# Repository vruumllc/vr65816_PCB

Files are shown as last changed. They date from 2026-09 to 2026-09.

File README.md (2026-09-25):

# vr65816

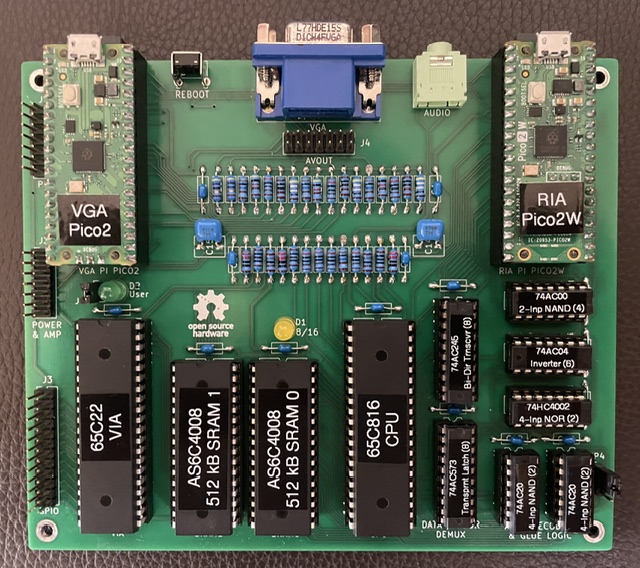
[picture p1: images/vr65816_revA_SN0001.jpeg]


WDC 65C816 Single Board Retro-Computer compatible with [Rumbledethump's Picocomputer Architecture](https://picocomputer.github.io/)

This project is based on [Rumbledethump's Picocomputer 6502 design](https://github.com/picocomputer/schematic), so he gets top billing. 

That said, any flaws are my fault, 'cause his board works GREAT! 

Report any problems to me using the ['Issues'](https://github.com/vruumllc/vr65816_schematic/issues) menu item above.

## Is the vr65816 for you?
Should you be building the vr65816 at all? This board is targeted at experienced programmers interested in exploring and exploiting the 65816 microprocessor. You might want to read the [Caveats](https://github.com/vruumllc/vr65816_schematic/blob/main/README.md#caveats) section at the end of this document before continuing. I built it because I wanted to create projects requiring more memory than the 64kB limit of the 8-bit 6502 processor, and I'm willing to experiment, and fail. 

If you aren't an experienced programmer, or just want to build an inexpensive but extremely capable retro-computer to re-live the exciting early days of the personal computer, then I'd strongly suggest starting with the Rumbledethump's Picocomputer 6502 (RP6502 for short). Order a PCB and support his project [here](https://ko-fi.com/rumbledethumps). 

## My goals for this project
- Use 2 [Rasberry Pi Pico2s](https://www.raspberrypi.com/products/raspberry-pi-pico-2/) with [Rumbledethumps' rp6502 firmware](https://github.com/picocomputer/rp6502)
- Run [WDC 65C816](https://www.westerndesigncenter.com/wdc/documentation/w65c816s.pdf) at up to 8Mhz, clocked by Pico2W RIA
- Use currently produced through-hole ICs only, and no programmable logic
- Use 1MB SRAM, 64kB extended RAM (on Pico2W RIA), and no hardware ROM
- Use [WDC 65C22](https://www.westerndesigncenter.com/wdc/documentation/w65c22s.pdf) for timers and peripheral I/O
- Design, [breadboard](https://github.com/vruumllc/vr65816_schematic/blob/main/images/vr65816_breadboard.jpg), and test it. 
- Run all existing apps and games ("[ROMs](https://discord.com/channels/534571197908647946/1487969279251841216)") for the Rumbledethumps' RP6502 Picocomputer
- Enable [creation](https://github.com/picocomputer/rp6502-sdk) of new "ROMs" utilizing [features and memory of the '816](https://archive.org/details/0893037893ProgrammingThe65816/mode/2up)
- Use [KiCad](https://www.kicad.org/download) to create fully open source schematic and board design files

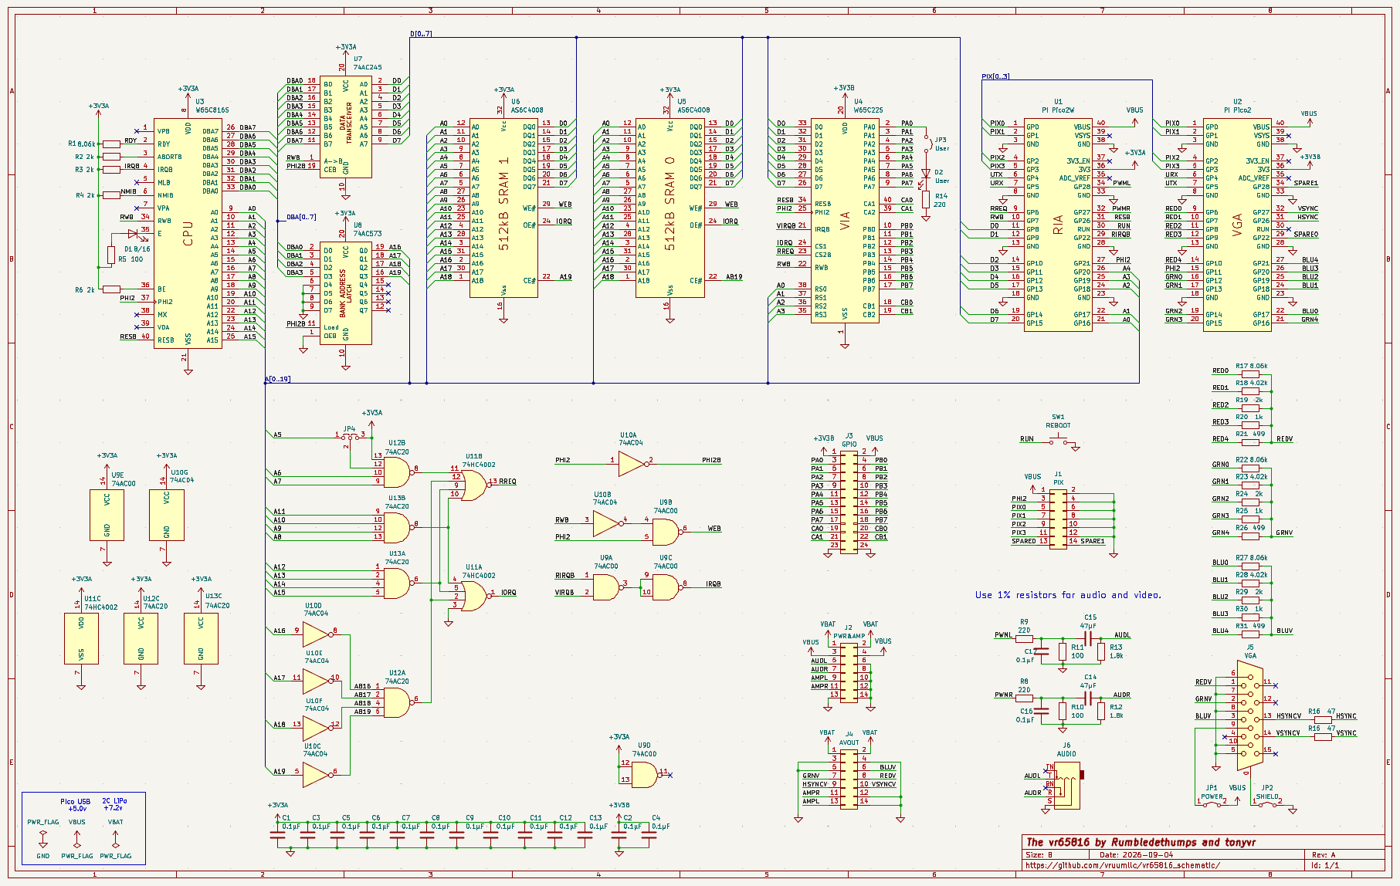
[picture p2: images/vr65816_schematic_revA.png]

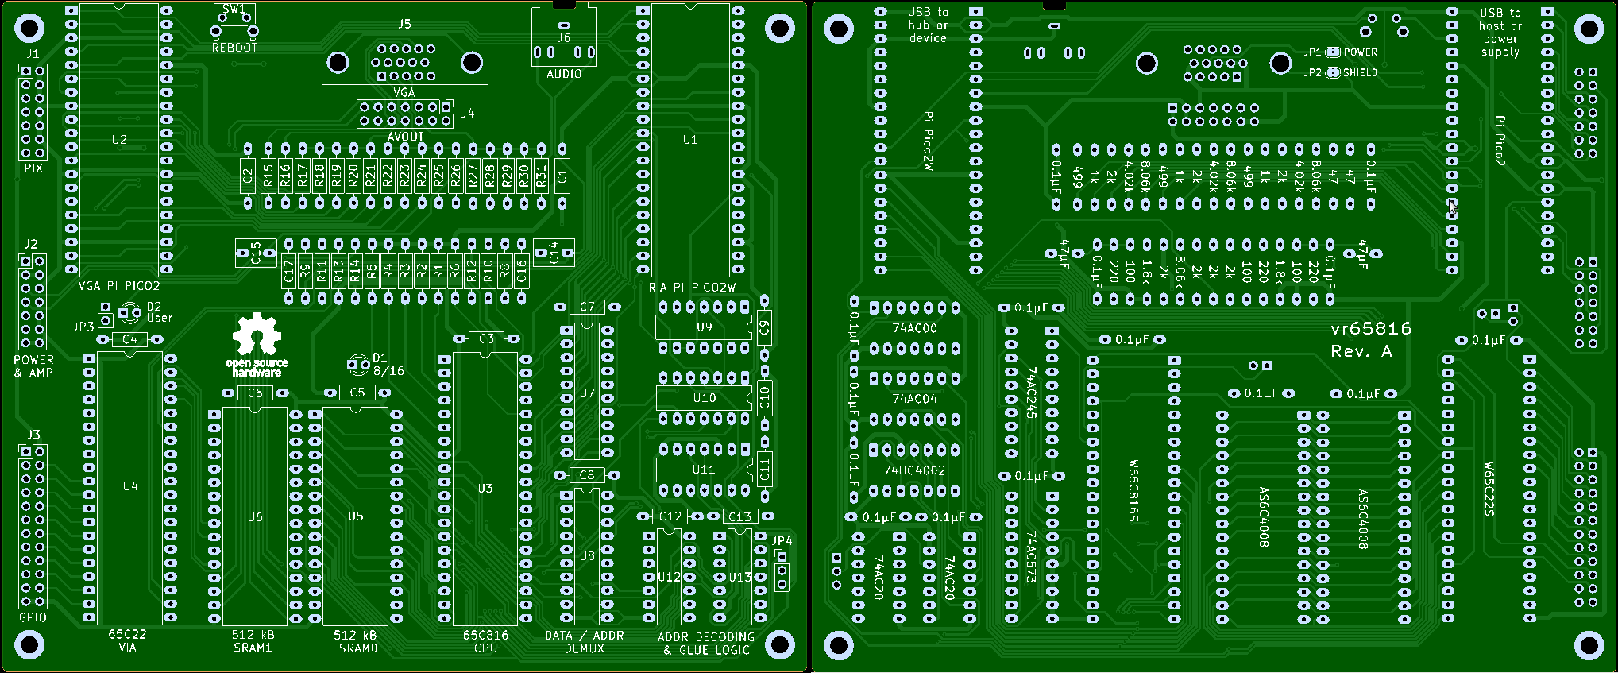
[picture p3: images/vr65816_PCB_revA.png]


## Getting the parts
I used [Mouser's 'Create a BOM'](https://www.mouser.com/en/Bom/) feature to order all parts except the PCB.  Use the 'Mouser Part Number' and 'Qty' columns from the [vr65816_full_BOM.csv](https://github.com/vruumllc/vr65816_schematic/blob/main/vr65816_full_BOM.csv) file in this repository.

You can also get the identical parts at [DigiKey](https://www.digikey.com/), except for the WDC 65C816 and 65C22.

My cost per kit of parts was about $124 USD, including shipping, fees, and taxes.

## Getting a PCB
I used [PCBWay](https://www.pcbway.com) to fabricate my PCB:
- Click on "PCB Prototype" at upper left after logging in
- Enter Length=125 and Width=150 mm for the Size
- Select Quantity desired (5 minimum)
- Select Solder Mask and Silkscreen Colors, Surface Finish, and 'Remove Product No.' as desired
- Press the 'Calculate' button at the bottom to generate a price quote
- If the price is right, press 'Save to Cart', then 'Agree' buttons
- Drag the [vr65816_gerbers.zip](https://github.com/vruumllc/vr65816_schematic/blob/main/vr65816_gerbers.zip) file into the web dialog, then click 'Submit the file now'

After a wait of a few minutes while the file is 'Under Review' you will be allowed to place your order.

My cost was about $105 USD including shipping, fees, and taxes -- about $21 USD per PCB.

The total price per vr65816 therefore came out to be about $145 USD (September 2026, Silicon Valley, USA).

## More things you need that you may already own
Rumbledethumps has made a huge effort to support modern hardware, so you don't have to rely on ancient and expensive peripherals to use this retro-computer. Here is a list of peripherals you may already have, with some example links if you don't:

(All links are just clarifying examples and not an endorsement or guarantee of compatibility)

- USB micro-B cable with either [A](https://www.adafruit.com/product/592) or [C](https://www.adafruit.com/product/3878) connector (depending upon what your desktop or laptop computer has)
- [USB-OTG Hub with micro-B connector](https://vilros.com/products/vilros-microusb-to-usb-4-port-otg-hub-black-great-for-pi-zero)
- USB2 flash drive formatted for FAT32 (or 'msdos' in Linux)
- Keyboard, Mouse and [Gamepad](https://www.logitechg.com/en-us/shop/p/f310-gamepad) (USB-2 cable or [wireless](https://www.logitech.com/en-us/shop/p/mk470-slim-wireless-keyboard-mouse), or Bluetooth LE)
- Stereo headphones or computer speakers
- VGA Monitor and cable

  OR
  
- HDMI Monitor, cable, and [VGA to HDMI adapter](https://ventiontech.com/products/vga-to-hdmi-adapter-1080p-vga-male-to-hdmi-female-converter-cable-with-audio-usb-power-for-ps4-3-hdtv-vga-hdmi-converter) (NOT HDMI to VGA adapter!!!)

## Building the vr65816 
On a scale from 1 to 10 for electronics kit build difficulty, the vr65816 ranks about a 3. While it is probably not the best project to learn soldering on, it is an easy kit to build -- well within the capabilities of a supervised middle-school student. The component identifications are all on the back of the PCB, and listed in the [BOM](https://github.com/vruumllc/vr65816_schematic/blob/main/vr65816_full_BOM.csv).

The hardest part is making sure you have the right resisters in the right places (consult a [resister color key](https://en.wikipedia.org/wiki/Electronic_color_code), or use an Ohm meter to make sure). Other than that, just make sure your sockets (and the chips inserted in them) are the correct direction as indicated by the notch on the PCB, and that the 2 LEDs are soldered with the shorter leg (with the flat) in the hole with the square solder pad (cathode in pin1). I guess the middle row of the VGA connector might be a little tricky if you don't have a fine tipped soldering iron...but...you can do this! 

## Uploading the Picocomputer firmware
Get the latest released firmware from [here](https://github.com/picocomputer/rp6502/releases). You want the file named rp6502-#.##-pico.zip, where #.## is the latest version number. 
- Unzip the files to a temporary folder on your host computer
- Plug the micro-B USB cable into the Pico 2W (the one with the rectangular metal shield around the wireless chip)
- Press and hold the BootSel button on the Pico 2W, then plug the other end of the cable into your host computer
- Release the BootSel button, and you should see a new drive appear on your host computer
- Copy (or drag) the rp6502-#.##-ria-w.uf2 file into the new drive
- The file should upload to the Pico 2W and turn it into the "RIA", lighting the LED.
- Repeat the process for the Pico 2, this time copying the rp6502-#.##-vga.uf2, creating the 'VGA card' for the vr65816.
- Unplug the USB cable from your host computer, leaving it connected to the Pico 2 VGA micro-B port

## Testing your vr65816
OK! You should now have a completed vr65816 retro-computer of your very own. Let's test it.
- Plug the USB 2 OTG hub into the micro-B port of the Pico 2W RIA
- On your host computer, copy the [test "ROM" files](https://github.com/vruumllc/vr65816_schematic/tree/main/test_ROMS) (ending in .rp6502 or .vr65816) from this repository into the USB flash drive
- Remove the USB flash drive from your host computer and plug it into the USB 2 OTG hub
- Plug in any other USB 2 peripherals like keyboard, mouse, and gamepad, if you have them
- Plug in the headphones or computer speakers, if you have them
- Plug in the video monitor if you have it, using the VGA to HDMI adapter if it is an HDMI monitor
- Finally, plug the USB cable connected to the Pico 2 VGA back into your host computer.

If you have a video monitor connected, you should see "Picocomputer 6502" and the RIA and VGA firmware versions you uploaded, followed by the prompt ']' and a blinking cursor.

If you don't have monitor, keyboard, mouse, gamepad, or speakers yet, don't worry.  You can still continue testing as long as you have the USB cable connected from the Pico 2 VGA to your host computer.  Besides powering the vr65816, this cable supplies a serial communication channel operating at 115200 baud, 8 data bits, 1 stop bit, no parity, and no flow control. You can use a serial terminal program on your host computer to interact with the vr65816. The details vary depending upon your host computer type. I use Linux and like GTKTerm. PuttySSH also works well and exists for both Linux and Windows. Sorry, I've never owned a Mac, so you are on your own.

If you've arrived at the ']', you've verified that the Pico half of the vr65816 is working.  You are looking at the prompt for the 'monitor' program (not to be confused with a computer display), which runs on the Pico 2W RIA. Try typing "help" to see all that it can do for you. 

You still haven't tested the 65816 half of the board, however. To do that, simply type "0" and return.  You should see the contents of the first 16 bytes of the 65816 memory, thus verifying that the RIA can talk to the 65816 microprocessor and access its memory.

Congratulations! Time to start having fun by loading some ROMs.

## Caveats
Rumbledethump's Picocomputer Architecture for the WDC 65C02 was developed over several YEARS and encompasses not just the RP6502 hardware and its firmware, but platform support on two C compilers, and a programming infrastructure developed for Microsoft's Visual Studio Code IDE (not to mention the emulators, FPGA implementation...).

All of this is a wonderful base for my project, but I went into it knowing that since it was developed for the 6502, that there would some limitations re-using it. I had NO intentions of forking any of his architecture, and instead would learn to work within the limitations. You should too. 

Here are some things to keep in mind before building my vr65816:

1. Rumbledethump has stated that he has no interest in the 65816. That means the vr65816 is a kind of a, umm, love child of his efforts. Please don't ask him to add any new features in support of this project.
2. Similarly, be considerate at the [Picocomputer 6502 Discord site](https://discord.com/channels/534571197908647946/1545859287706902559). Rumbledethumps has created an '#other-hardware' channel for projects like mine. Please use it. I'll keep on eye on it.
3. Very importantly, neither C compiler supporting the RP6502 compiles for the 65816. The ca65 assembler piece of the [cc65 project](https://cc65.github.io/) DOES understand 65816 assembly, though, as does [llvm-mos's](https://llvm-mos.org/wiki/Welcome) assembler. This means that to exploit the 16-bit features and memory of the vr65816, you will need to code in assembly language. I plan to put 'best practice' examples in the [vr65816_examples](https://github.com/vruumllc/vr65816_examples) repository. I could really use help developing these, as I know relatively little about assembly language programming.
4. Unfortunately, the 6502 memory locations reserved for the 'RIA registers', used to communicate between the Pico 2W RIA and the 6502, overlap the 65816 16-bit interrupt vectors. That limits us to throwing interrupts only while in 8-bit mode. As a very last resort, I added the mysterious jumper JP4, which increases the space for the RIA registers enough to shift them down. This would mean #defining all the register locations in the firmware and compilers, and breaking compatibility with 6502 ROMs, which I really, really, really don't want to do.
5. The RIA can only access the lowest 64kB of memory, so each 65816 ROM will have to be responsible for loading its assets and code into higher memory. Large 65816 projects will need to be designed so that the initially loaded portion is less than 64kB.
6. 65816 ROMs will have to check programatically to make sure they are not accidentally loaded into an RP6502. The ROMS must exit gracefully with a message if so. The monitor program handles loading ROMs renamed to have a .vr65816 extension, so that might help to avoid confusion.
7. The monitor program can only dump the lowest 64kB of microcontroller memory (65816 Bank0), and displays the 64kB of extended RAM living on the RIA using the 65816 Bank1 addresses. Confusing, but if dumping any 65816 upper memory is needed, a 65816-specific ROM can be written.
8. The emulators written thus far only support the RP6502.
9. The vr65816 PCB is 25mm taller than the RP6502 PCB, so it won't fit in the fabulous 3D-printed cases I've already designed. If I ever finish working on this README and the vr65816_examples, I'll hop right to it and come up with something special.
10. I'm sure more things will come to light...

Don't get too discouraged by all this. At the very least you'll wind up with a retro-computer compatible with the RP6502, which (have I already mentioned this?) is really GREAT!

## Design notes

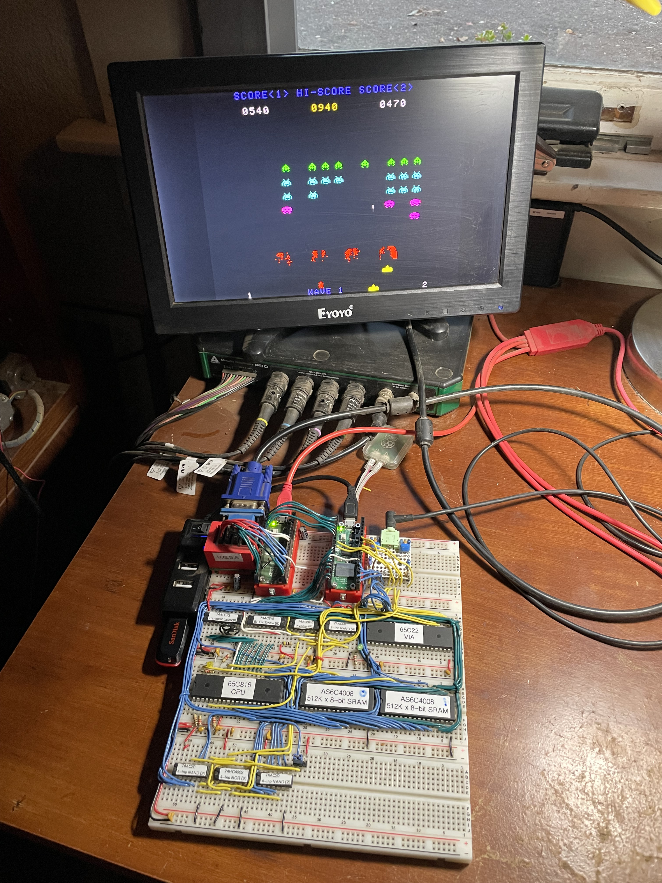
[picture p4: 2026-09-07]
images/vr65816_breadboard.jpg

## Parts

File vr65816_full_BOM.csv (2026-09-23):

Qty | Reference | Description | Mfr Name | Mfr Part Number | Mouser Part Number | DigiKey Part Number
15 | C1, C2, C3, C4, C5, C6, C7, C8, C9, C10, C11, C12, C13, C16, C17 | 0.1μF Ceramic Capacitor | Vishay | A104M15X7RF5TAA | 594-A104M15X7RF5TAA | BC5250CT-ND
2 | C14, C15 | 47μF Ceramic Capacitor | TDK | FG22X5R1A476MNT06 | 810-FG22X5R1A476MNT6 | 445-173314-1-ND
1 | D1 | 5.0mm LED, yellow, tinted, diffused | Broadcom / Avago | HLMP-3401 | 630-HLMP-3401 | 516-1331-ND
1 | D2 | 5.0mm LED, green, tinted, diffused | Broadcom / Avago | HLMP-3507 | 630-HLMP-3507 | 516-1333-ND
4 | R1, R17, R22, R27 | 8.06k resistor 1% | YAGEO | MFR-25FBF52-8K06 | 603-MFR-25FBF52-8K06 | 8.06KXBK-ND
3 | R18, R23, R28 | 4.02k resistor 1% | YAGEO | MFR-25FBF52-4K02 | 603-MFR-25FBF52-4K02 | 4.02KXBK-ND
7 | R2, R3, R4, R6, R19, R24, R29 | 2k resistor 1% | YAGEO | MFR-25FBF52-2K | 603-MFR-25FBF52-2K | 2.00KXBK-ND
2 | R12, R13 | 1.8k resistor 1% | YAGEO | MFR-25FBF52-1K8 | 603-MFR-25FBF52-1K8 | 13-MFR-25FBF52-1K8-ND
3 | R20, R25, R30 | 1k resistor 1% | YAGEO | MFR-25FBF52-1K | 603-MFR-25FBF52-1K | 1.00KXBK-ND
3 | R21, R26, R31 | 499 ohm resistor 1% | YAGEO | MFR-25FBF52-499R | 603-MFR-25FBF52-499R | 499XBK-ND
3 | R8, R9, R14 | 220 ohm resistor 1% | YAGEO | MFR-25FBF52-220R | 603-MFR-25FBF52-220R | MFR-25FBF52-220R-ND
3 | R5, R10, R11 | 100 ohm resistor 1% | YAGEO | MFR-25FBF52-100R | 603-MFR-25FBF52-100R | 100XBK-ND
2 | R15, R16 | 47 ohm resistor 1% | YAGEO | MFR-25FBF52-47R | 603-MFR-25FBF52-47R | MFR-25FBF52-47R-ND
1 | U1 | Pico 2W (no Headers) | Raspberry Pi | SC1633 | 358-SC1633 | 2648-SC1633CT-ND
1 | U2 | Pico 2 (no Headers) | Raspberry Pi | SC1631 | 358-SC1631 | 2648-SC1631CT-ND
1 | U3 | WDC W65C816S | WDC | W65C816S6PG-14 | 955-W65C816S6PG-14
1 | U4 | WDC W65C22S | WDC | W65C22S6TPG-14 | 955-W65C22S6TPG-14
2 | U5, U6 | 512k SRAM AS6C4008 | Alliance | AS6C4008-55PCN | 913-AS6C4008-55PCN | 1450-1027-ND
1 | U7 | 74AC245 Octal Tri-State Bus Transceiver | TI | CD74AC245E | 595-CD74AC245E | 296-32959-5-ND
1 | U8 | 74AC573 Octal Transparent Latch, 3-State | TI | CD74AC573E | 595-CD74AC573E | 296-1379-5-ND
1 | U9 | 74AC00 Quad NAND | TI | CD74AC00E | 595-CD74AC00E | 296-4214-5-ND
1 | U10 | 74AC04 Hex Inverter | TI | CD74AC04E | 595-CD74AC04E | 296-4217-5-ND
1 | U11 | 74HC4002 Dual 4 input NOR | TI | CD74HC4002E | 595-CD74HC4002E | 296-25987-5-ND
2 | U12, U13 | 74AC20 Dual 4 Input NAND | TI | CD74AC20E | 595-CD74AC20E | 296-4237-5-ND
3 | J1, J2, J4 | PIX,PWR&AMP,AVOUT 2x8 Pin headers | Amp | 10129381-914001BLF | 649-1012938191401BLF | 10129381-914001BLF-ND
1 | J3 | GPIO 2x12 Pin Header | Amp | 10129381-924001BLF | 649-1012938192401BLF | 10129381-924001BLF-ND
1 | JP4 | 1x2 Jumper | Amp | 10129378-902001BLF | 649-1012937890201BLF | 10129378-902001BLF-ND
1 | JP3 | 1x3 Jumper | Amp | 10129378-903001BLF | 649-1012937890301BLF | 10129378-903001BLF-ND
2 | JP3, JP4 | Jumper Socket | Harwin | 855-M7567-46 | 855-M7567-46 | 952-2165-ND
4 | U1, U2 | Pico 20 Pin Socket | Wurth | 61302011821 | 710-61302011821 | 732-61302011821-ND
4 | U1, U2 | Pico 1x20 Pin Header | Amp | 10129378-920001BLF | 649-1012937892001BLF | 10129378-920001BLF-ND
2 | U1, U2 | 1x3 Right-Angle Header | Molex | 22-28-8032 | 538-22-28-8032 | WM50015-03-ND
1 | J3 | VGA Jack | Amp | L77HDE15SD1CH4FVGA | 523-7HDE15SD1CH4FVGA | L77HDE15SD1CH4FVGA-ND
1 | J4 | Audio Jack | CUI | SJ1-3525NG-GR | 490-SJ1-3525NG-GR | CP1-3525NG-GR-ND
1 | SW1 | Reset Button | CUI | TS11-674-43-BK-160-RA-D | 179-TS1167443160RAD | 2223-TS11-674-43-BK-160-RA-D-ND
5 | U9, U10, U11, U12, U13 | 14-pin IC Socket | TE | 1-2199298-3 | 571-1-2199298-3 | A120348-ND
1 | U8 | 16-pin IC Socket | TE | 1-2199298-4 | 571-1-2199298-4 | A120349-ND
1 | U7 | 20-pin IC Socket | TE | 1-2199298-6 | 571-1-2199298-6 | A120351-ND
2 | U5, U6 | 32-pin IC Socket | TE | 1-2199300-2 | 571-1-2199300-2 | A120356-ND
2 | U3, U4 | 40-pin IC Socket | TE | 1-2199299-5 | 571-1-2199299-5 | A120355-ND
4 | PCB | Stick-on Bumper Feet | Essentra | ASPR-8-125 | 144-ASPR-8-125 | RPC1912-ND

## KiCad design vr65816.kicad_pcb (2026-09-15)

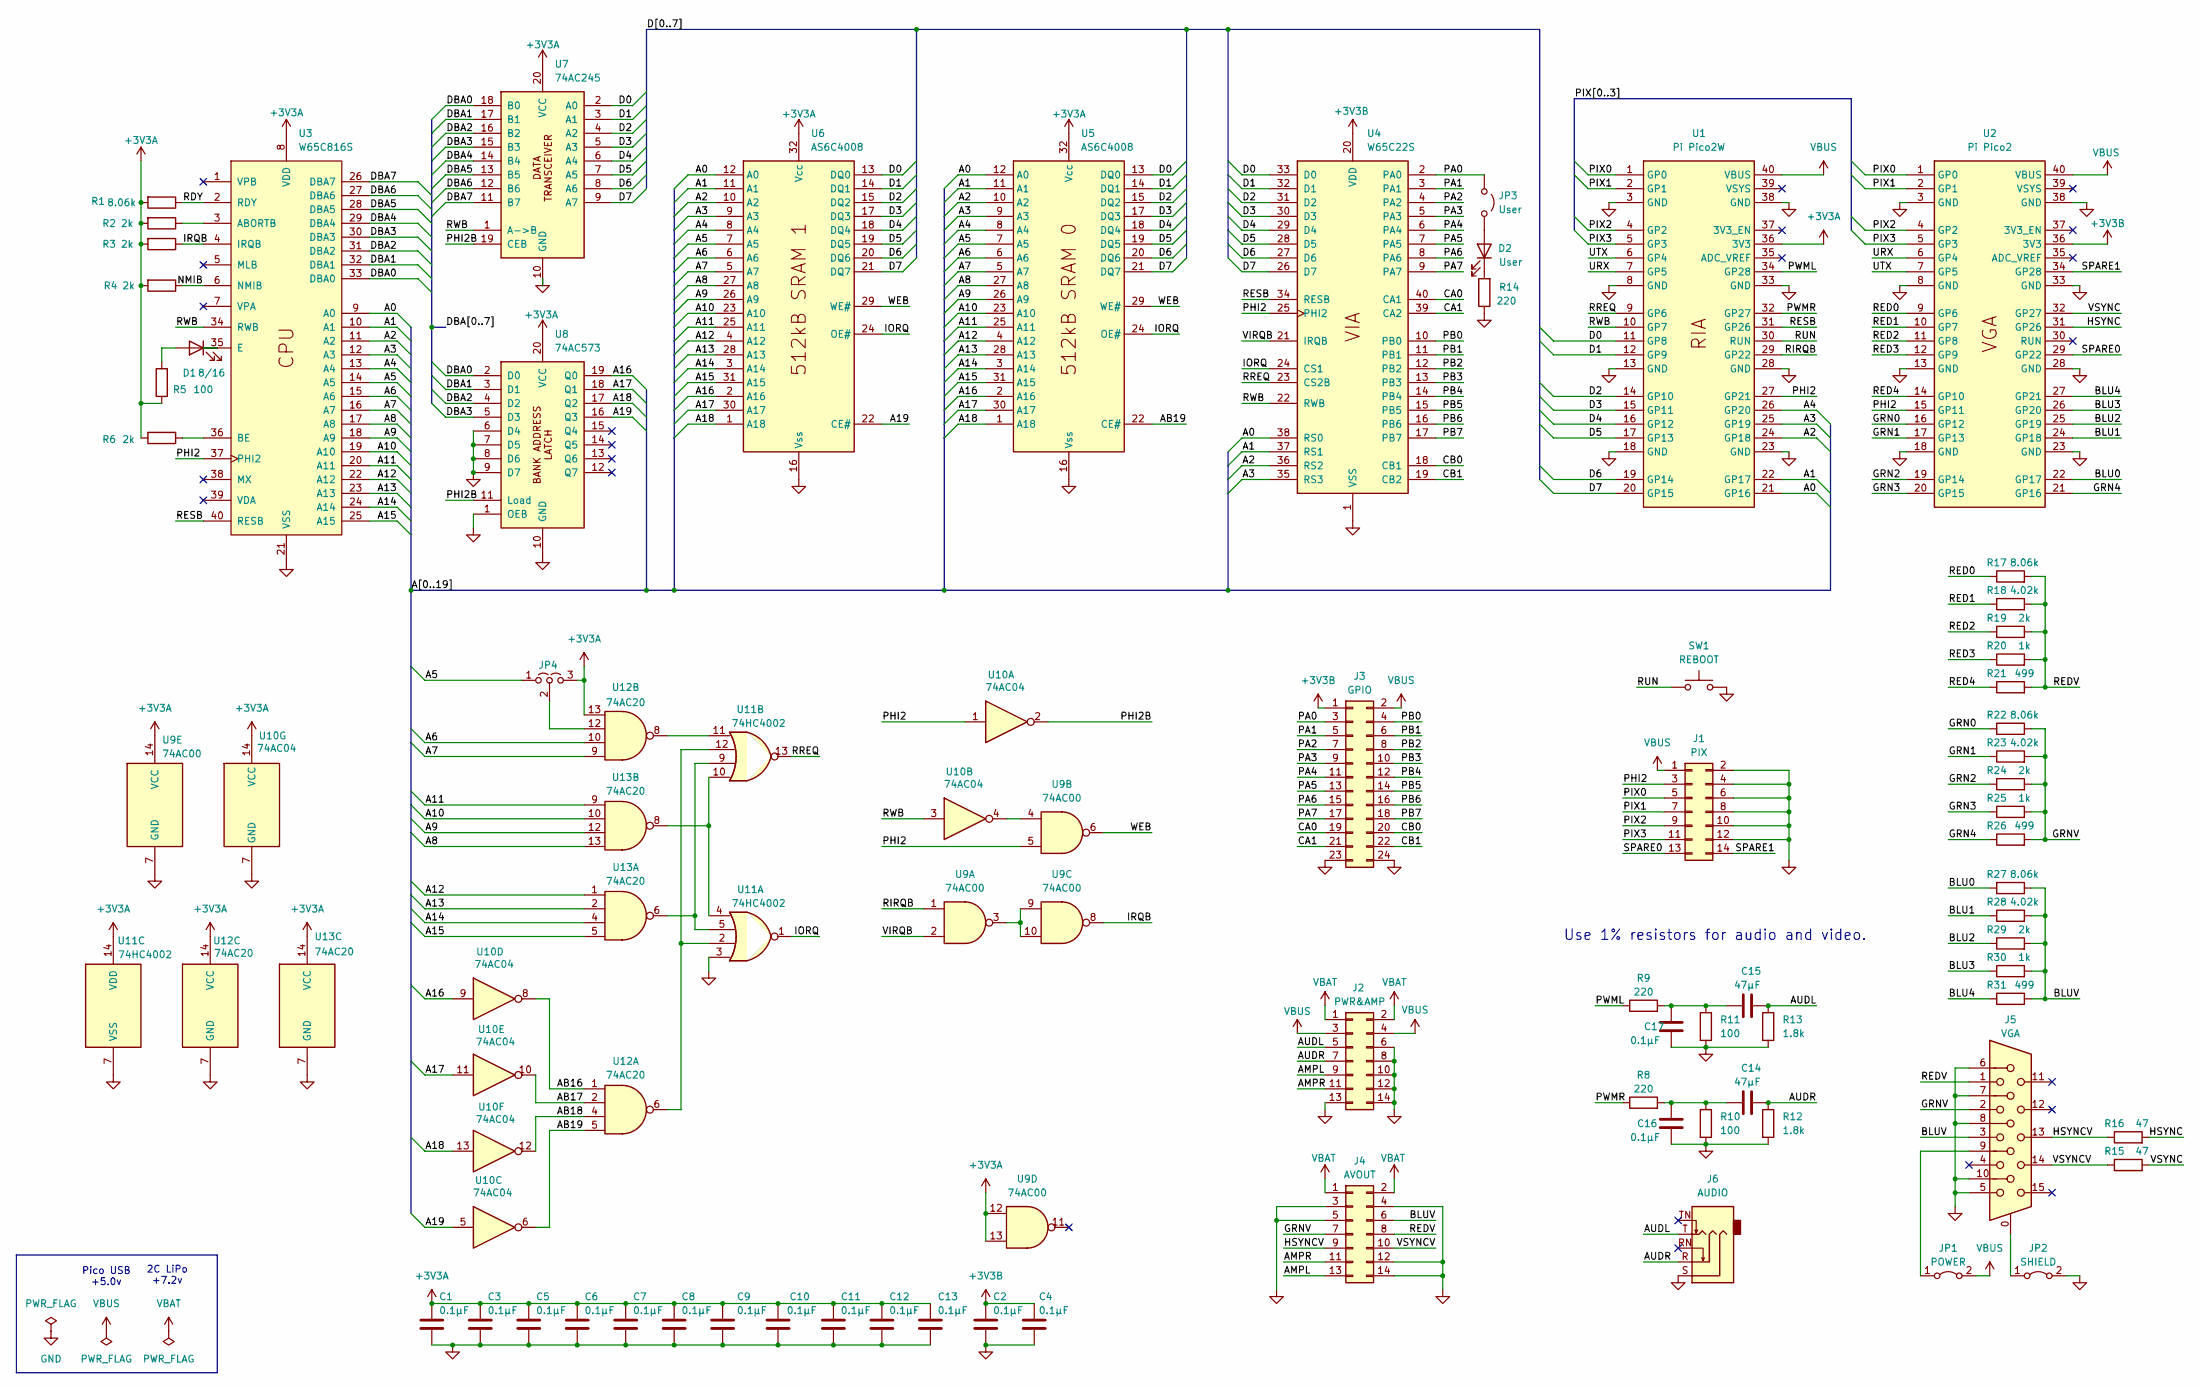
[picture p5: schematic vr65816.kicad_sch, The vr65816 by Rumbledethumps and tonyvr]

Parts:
C1, C2, C3, C4, C5, C6, C7, C8, C9, C10, C11, C12, C13, C16, C17: 0.1μF; R_Axial_DIN0207_L6.3mm_D2.5mm_P10.16mm_Horizontal_Long
C14, C15: 47μF; C_Disc_D7.5mm_W5.0mm_P5.00mm_Long
D1: 8/16; LED_D3.0mm
D2: User; LED_D3.0mm
J1: PIX; PinHeader_2x07_P2.54mm_Vertical
J2: PWR&AMP; PinHeader_2x07_P2.54mm_Vertical
J3: GPIO; PinHeader_2x12_P2.54mm_Vertical
J4: AVOUT; PinHeader_2x07_P2.54mm_Vertical
J5: VGA; DSUB-15-HD_Female_Horizontal_P2.29x2.54mm_EdgePinOffset8.35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
J6: AUDIO; Jack_3.5mm_CUI_SJ1-3525N_Horizontal
JP1: POWER; SolderJumper-2_P1.3mm_Bridged2Bar_RoundedPad1.0x1.5mm
JP2: SHIELD; SolderJumper-2_P1.3mm_Bridged2Bar_RoundedPad1.0x1.5mm
JP3: User; PinHeader_1x02_P2.54mm_Vertical
JP4: 3,[2,1]; PinHeader_1x03_P2.54mm_Vertical
R1, R17, R22, R27: 8.06k; R_Axial_DIN0207_L6.3mm_D2.5mm_P10.16mm_Horizontal_Long
R2, R3, R4, R6, R19, R24, R29: 2k; R_Axial_DIN0207_L6.3mm_D2.5mm_P10.16mm_Horizontal_Long
R5, R10, R11: 100; R_Axial_DIN0207_L6.3mm_D2.5mm_P10.16mm_Horizontal_Long
R8, R9, R14: 220; R_Axial_DIN0207_L6.3mm_D2.5mm_P10.16mm_Horizontal_Long
R12, R13: 1.8k; R_Axial_DIN0207_L6.3mm_D2.5mm_P10.16mm_Horizontal_Long
R15, R16: 47; R_Axial_DIN0207_L6.3mm_D2.5mm_P10.16mm_Horizontal_Long
R18, R23, R28: 4.02k; R_Axial_DIN0207_L6.3mm_D2.5mm_P10.16mm_Horizontal_Long
R20, R25, R30: 1k; R_Axial_DIN0207_L6.3mm_D2.5mm_P10.16mm_Horizontal_Long
R21, R26, R31: 499; R_Axial_DIN0207_L6.3mm_D2.5mm_P10.16mm_Horizontal_Long
SW1: REBOOT; SW_Tactile_SKHH_Angled
U1: Pi Pico2W; DIP-40_W17.78mm_LongPads
U2: Pi Pico2; DIP-40_W17.78mm_LongPads
U3: W65C816S; DIP-40_W15.24mm_LongPads
U4: W65C22S; DIP-40_W15.24mm_LongPads
U5, U6: AS6C4008; DIP-32_W15.24mm_LongPads
U7: 74AC245; DIP-20_W7.62mm_LongPads
U8: 74AC573; DIP-20_W7.62mm_LongPads
U9: 74AC00; DIP-14_W7.62mm_LongPads
U10: 74AC04; DIP-14_W7.62mm_LongPads
U11: 74HC4002; DIP-14_W7.62mm_LongPads
U12, U13: 74AC20; DIP-14_W7.62mm_LongPads

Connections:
+3V3A: C1.1, C3.1, C5.1, C6.1, C7.1, C8.1, C9.1, C10.1, C11.1, C12.1, C13.1, JP4.3 (B), R1.2, R2.2, R3.2, R4.2, R5.1, R6.2, U1.36 (3V3), U3.8 (VDD), U5.32 (Vcc), U6.32 (Vcc), U7.20 (VCC), U8.20 (VCC), U9.12, U9.13, U9.14 (VCC), U10.14 (VCC), U11.14 (VDD), U12.13, U12.14 (VCC), U13.14 (VCC)
+3V3B: C2.1, C4.2, J3.1, U2.36 (3V3), U4.20 (VDD)
/A0: U1.21 (GP16), U3.9 (A0), U4.38 (RS0), U5.12 (A0), U6.12 (A0)
/A1: U1.22 (GP17), U3.10 (A1), U4.37 (RS1), U5.11 (A1), U6.11 (A1)
/A2: U1.24 (GP18), U3.11 (A2), U4.36 (RS2), U5.10 (A2), U6.10 (A2)
/A3: U1.25 (GP19), U3.12 (A3), U4.35 (RS3), U5.9 (A3), U6.9 (A3)
/A4: U1.26 (GP20), U3.13 (A4), U5.8 (A4), U6.8 (A4)
/A5: JP4.1 (A), U3.14 (A5), U5.7 (A5), U6.7 (A5)
/A6: U3.15 (A6), U5.6 (A6), U6.6 (A6), U12.10
/A7: U3.16 (A7), U5.5 (A7), U6.5 (A7), U12.9
/A8: U3.17 (A8), U5.27 (A8), U6.27 (A8), U13.13
/A9: U3.18 (A9), U5.26 (A9), U6.26 (A9), U13.12
/A10: U3.19 (A10), U5.23 (A10), U6.23 (A10), U13.10
/A11: U3.20 (A11), U5.25 (A11), U6.25 (A11), U13.9
/A12: U3.22 (A12), U5.4 (A12), U6.4 (A12), U13.1
/A13: U3.23 (A13), U5.28 (A13), U6.28 (A13), U13.2
/A14: U3.24 (A14), U5.3 (A14), U6.3 (A14), U13.4
/A15: U3.25 (A15), U5.31 (A15), U6.31 (A15), U13.5
/A16: U5.2 (A16), U6.2 (A16), U8.19 (Q0), U10.9
/A17: U5.30 (A17), U6.30 (A17), U8.18 (Q1), U10.11
/A18: U5.1 (A18), U6.1 (A18), U8.17 (Q2), U10.13
/A19: U6.22 (CE#), U8.16 (Q3), U10.5
/AB16: U10.8, U12.1
/AB17: U10.10, U12.2
/AB18: U10.12, U12.4
/AB19: U5.22 (CE#), U10.6, U12.5
/AMPL: J2.9, J4.13
/AMPR: J2.11, J4.11
/AUDL: C15.2, J2.5, J6.T, R13.1
/AUDR: C14.2, J2.7, J6.R, R12.1
/BLU0: R27.1, U2.22 (GP17)
/BLU1: R28.1, U2.24 (GP18)
/BLU2: R29.1, U2.25 (GP19)
/BLU3: R30.1, U2.26 (GP20)
/BLU4: R31.1, U2.27 (GP21)
/BLUV: J4.6, J5.3, R27.2, R28.2, R29.2, R30.2, R31.2
/CA0: J3.19, U4.40 (CA1)
/CA1: J3.21, U4.39 (CA2)
/CB0: J3.20, U4.18 (CB1)
/CB1: J3.22, U4.19 (CB2)
/D0: U1.11 (GP8), U4.33 (D0), U5.13 (DQ0), U6.13 (DQ0), U7.2 (A0)
/D1: U1.12 (GP9), U4.32 (D1), U5.14 (DQ1), U6.14 (DQ1), U7.3 (A1)
/D2: U1.14 (GP10), U4.31 (D2), U5.15 (DQ2), U6.15 (DQ2), U7.4 (A2)
/D3: U1.15 (GP11), U4.30 (D3), U5.17 (DQ3), U6.17 (DQ3), U7.5 (A3)
/D4: U1.16 (GP12), U4.29 (D4), U5.18 (DQ4), U6.18 (DQ4), U7.6 (A4)
/D5: U1.17 (GP13), U4.28 (D5), U5.19 (DQ5), U6.19 (DQ5), U7.7 (A5)
/D6: U1.19 (GP14), U4.27 (D6), U5.20 (DQ6), U6.20 (DQ6), U7.8 (A6)
/D7: U1.20 (GP15), U4.26 (D7), U5.21 (DQ7), U6.21 (DQ7), U7.9 (A7)
/DBA0: U3.33 (DBA0), U7.18 (B0), U8.2 (D0)
/DBA1: U3.32 (DBA1), U7.17 (B1), U8.3 (D1)
/DBA2: U3.31 (DBA2), U7.16 (B2), U8.4 (D2)
/DBA3: U3.30 (DBA3), U7.15 (B3), U8.5 (D3)
/DBA4: U3.29 (DBA4), U7.14 (B4)
/DBA5: U3.28 (DBA5), U7.13 (B5)
/DBA6: U3.27 (DBA6), U7.12 (B6)
/DBA7: U3.26 (DBA7), U7.11 (B7)
/GRN0: R22.1, U2.16 (GP12)
/GRN1: R23.1, U2.17 (GP13)
/GRN2: R24.1, U2.19 (GP14)
/GRN3: R25.1, U2.20 (GP15)
/GRN4: R26.1, U2.21 (GP16)
/GRNV: J4.7, J5.2, R22.2, R23.2, R24.2, R25.2, R26.2
/HSYNC: R16.2, U2.31 (GP26)
/HSYNCV: J4.9, J5.13, R16.1
/IORQ: U4.24 (CS1), U5.24 (OE#), U6.24 (OE#), U11.1
/IRQB: R3.1, U3.4 (IRQB), U9.8
/NMIB: R4.1, U3.6 (NMIB)
/PA0: J3.3, JP3.1 (A), U4.2 (PA0)
/PA1: J3.5, U4.3 (PA1)
/PA2: J3.7, U4.4 (PA2)
/PA3: J3.9, U4.5 (PA3)
/PA4: J3.11, U4.6 (PA4)
/PA5: J3.13, U4.7 (PA5)
/PA6: J3.15, U4.8 (PA6)
/PA7: J3.17, U4.9 (PA7)
/PB0: J3.4, U4.10 (PB0)
/PB1: J3.6, U4.11 (PB1)
/PB2: J3.8, U4.12 (PB2)
/PB3: J3.10, U4.13 (PB3)
/PB4: J3.12, U4.14 (PB4)
/PB5: J3.14, U4.15 (PB5)
/PB6: J3.16, U4.16 (PB6)
/PB7: J3.18, U4.17 (PB7)
/PHI2: J1.3, U1.27 (GP21), U2.15 (GP11), U3.37 (PHI2), U4.25 (PHI2), U9.5, U10.1
/PHI2B: U7.19 (CEB), U8.11 (Load), U10.2
/PIX0: J1.5, U1.1 (GP0), U2.1 (GP0)
/PIX1: J1.7, U1.2 (GP1), U2.2 (GP1)
/PIX2: J1.9, U1.4 (GP2), U2.4 (GP2)
/PIX3: J1.11, U1.5 (GP3), U2.5 (GP3)
/PWML: R9.1, U1.34 (GP28)
/PWMR: R8.1, U1.32 (GP27)
/RDY: R1.1, U3.2 (RDY)
/RED0: R17.1, U2.9 (GP6)
/RED1: R18.1, U2.10 (GP7)
/RED2: R19.1, U2.11 (GP8)
/RED3: R20.1, U2.12 (GP9)
/RED4: R21.1, U2.14 (GP10)
/REDV: J4.8, J5.1, R17.2, R18.2, R19.2, R20.2, R21.2
/RESB: U1.31 (GP26), U3.40 (RESB), U4.34 (RESB)
/RIRQB: U1.29 (GP22), U9.1
/RREQ: U1.9 (GP6), U4.23 (CS2B), U11.13
/RUN: SW1.2, U1.30 (RUN)
/RWB: U1.10 (GP7), U3.34 (RWB), U4.22 (RWB), U7.1 (A->B), U10.3
/SPARE0: J1.13, U2.29 (GP22)
/SPARE1: J1.14, U2.34 (GP28)
/URX: U1.7 (GP5), U2.6 (GP4)
/UTX: U1.6 (GP4), U2.7 (GP5)
/VIRQB: U4.21 (IRQB), U9.2
/VSYNC: R15.2, U2.32 (GP27)
/VSYNCV: J4.10, J5.14, R15.1
/WEB: U5.29 (WE#), U6.29 (WE#), U9.6
GND: C1.2, C2.2, C3.2, C4.1, C5.2, C6.2, C7.2, C8.2, C9.2, C10.2, C11.2, C12.2, C13.2, C16.2, C17.2, J1.2, J1.4, J1.6, J1.8, J1.10, J1.12, J2.6, J2.8, J2.10, J2.12, J2.13, J2.14, J3.23, J3.24, J4.3, J4.4, J4.5, J4.12, J4.14, J5.5, J5.6, J5.7, J5.8, J5.10, J6.S, JP2.2 (B), R10.2, R11.2, R12.2, R13.2, R14.1, SW1.1, U1.3 (GND), U1.8 (GND), U1.13 (GND), U1.18 (GND), U1.23 (GND), U1.28 (GND), U1.33 (GND), U1.38 (GND), U2.3 (GND), U2.8 (GND), U2.13 (GND), U2.18 (GND), U2.23 (GND), U2.28 (GND), U2.33 (GND), U2.38 (GND), U3.21 (VSS), U4.1 (VSS), U5.16 (Vss), U6.16 (Vss), U7.10 (GND), U8.1 (OEB), U8.6 (D4), U8.7 (D5), U8.8 (D6), U8.9 (D7), U8.10 (GND), U9.7 (GND), U10.7 (GND), U11.3, U11.7 (VSS), U12.7 (GND), U13.7 (GND)
unnamed: C14.1, C16.1, R8.2, R10.1
unnamed: C15.1, C17.1, R9.2, R11.1
unnamed: D1.2 (A), R5.2
unnamed: D1.1 (K), U3.35 (E)
unnamed: D2.2 (A), JP3.2 (B)
unnamed: D2.1 (K), R14.2
unnamed: J5.9, JP1.1 (A)
unnamed: J5.0, JP2.1 (A)
unnamed: JP4.2 (C), U12.12
unnamed: R2.1, U3.3 (ABORTB)
unnamed: R6.1, U3.36 (BE)
unnamed: U9.3, U9.9, U9.10
unnamed: U9.4, U10.4
unnamed: U11.5, U11.9, U13.6
unnamed: U11.4, U11.10, U13.8
unnamed: U11.11, U12.8
unnamed: U11.2, U11.12, U12.6
VBAT: J2.1, J2.2, J4.1, J4.2
VBUS: J1.1, J2.3, J2.4, J3.2, JP1.2 (B), U1.40 (VBUS), U2.40 (VBUS)

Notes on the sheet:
Use 1% resistors for audio and video.
Pico USB +5.0v
2C LiPo +7.2v

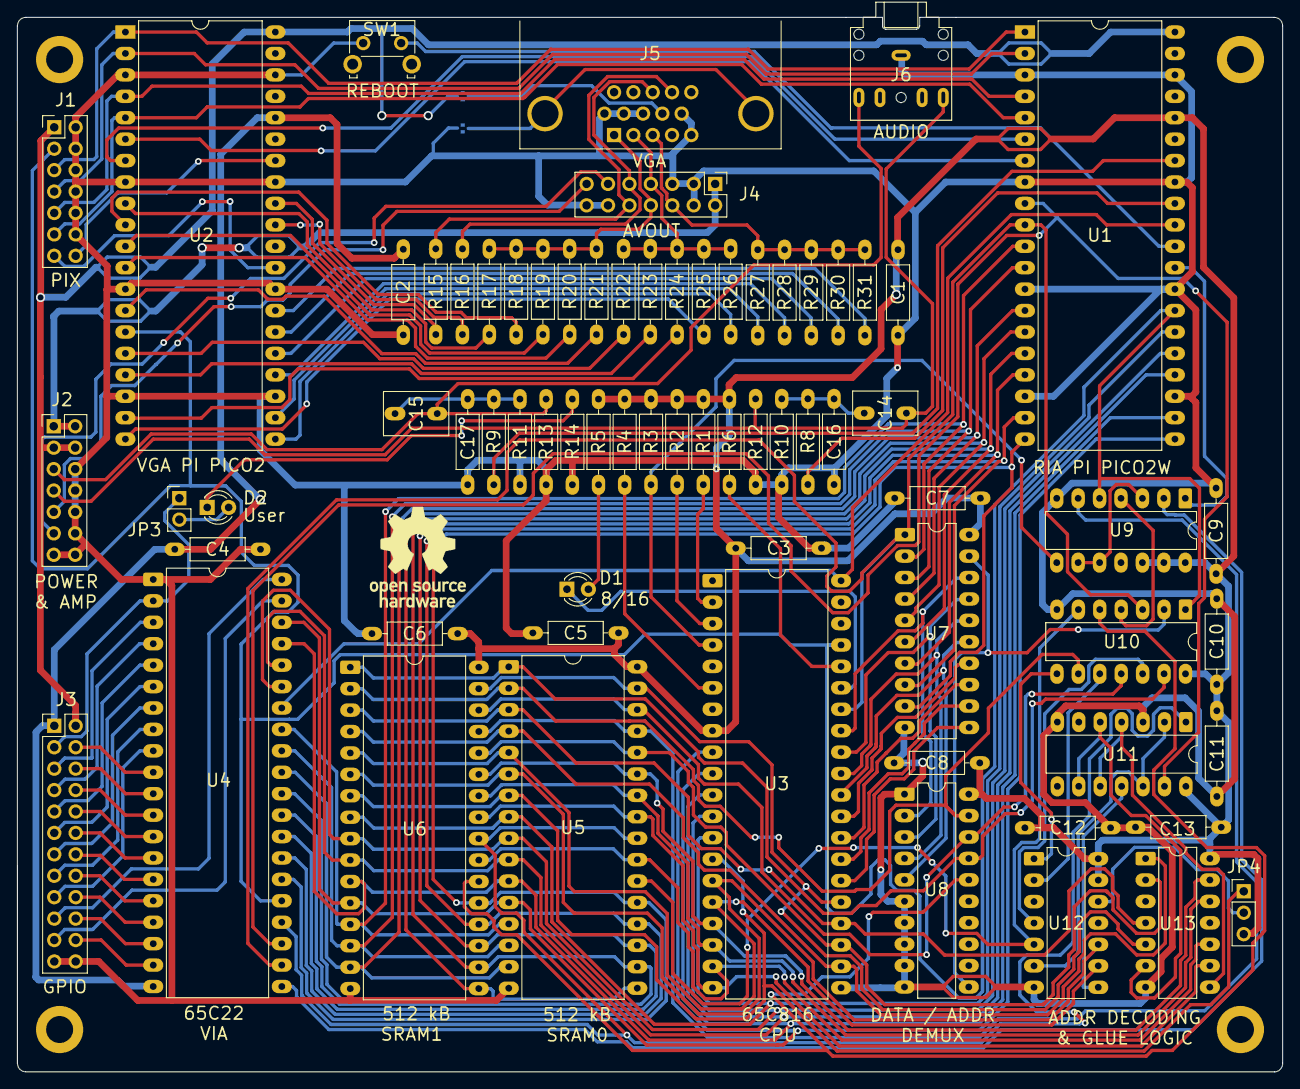
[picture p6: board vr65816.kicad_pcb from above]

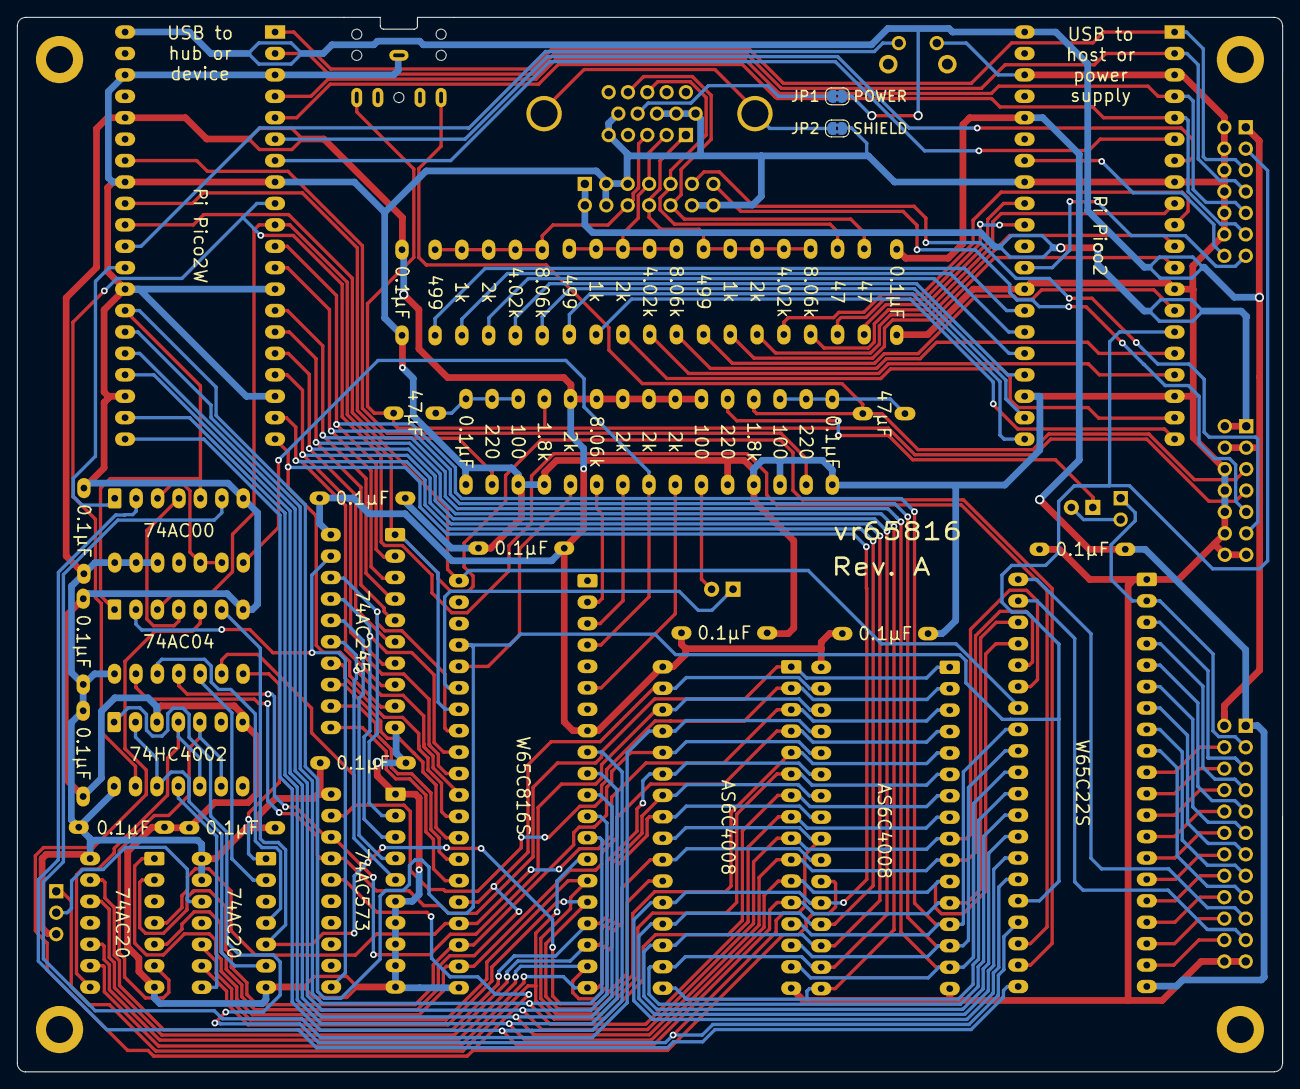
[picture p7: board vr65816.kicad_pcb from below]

Board: 2 copper layers, 150.0 x 125.0 mm, 73 parts (2 on the bottom side), 131 nets.
